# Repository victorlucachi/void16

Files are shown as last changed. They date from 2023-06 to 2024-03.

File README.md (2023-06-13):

# VOID16
*A 4x4 handwired macropad*

VOID16

The VOID16 is a 3d printed, handwired, 4x4 macropad running QMK Firmware on a Pro Micro controller.

I suggest printing the case using a 0.4 mm nozzle, supports are not needed for any of the parts.

You might want/need to use small dabs of hot glue to secure the switches in the plate depending on how well calibrated your printer is (if you're generous with it, it will add to the weight of the keyboard and it might change the feel of it).

Dont overtighten the screws as the threads might get stripped.

# Handwiring guide

I've also put together a pretty visual handwiring guide for the VOID9, that you can browse over [here](https://victorlucachi.ro/journal/void9-wiring-guide/).

|  	|  	|  	|
|---|---|---|

# Bill Of Materials

* 16 x diodes ([tme.eu](https://www.tme.eu/ro/en/details/1n4148-dio/tht-universal-diodes/diotec-semiconductor/1n4148/)/[aliexpress](https://www.aliexpress.com/item/32729204179.html))
* 16 x Cherry MX style mechanical switches
* 16 x keycaps of choice
* 1 x Pro Micro ([aliexpress](https://www.aliexpress.com/item/32902569443.html))
* 1 x EC11 Rotary Encoder ([aliexpress](https://www.aliexpress.com/item/32872039030.html)/mounted to the plate using [this adapter](https://www.thingiverse.com/thing:3770166))
* 24 AWG (0.2 mm2) wire
* 4 x 8mm bumpons

### Redux
* 6 x M2x3x3.5 OD heat inserts ([aliexpress](https://www.aliexpress.com/item/4000585933306.html?spm=a2g0o.order_list.order_list_main.33.21ef1802vdSNrS))
* 4 x M2x10 Allen head screws ([aliexpress](https://www.aliexpress.com/item/32966941844.html?spm=a2g0o.order_detail.order_detail_item.9.722ff19cyjrixq))
* 2 x M2x6 Countersunk screws ([aliexpress](https://www.aliexpress.com/item/32968097507.html?spm=a2g0o.order_list.order_list_main.32.21ef1802vdSNrS))

### V1
* 4 x M3x10 allen head screws ([tme.eu](https://www.tme.eu/ro/en/details/m3x10_d912-a2/bolts/kraftberg/)/[aliexpress](https://www.aliexpress.com/item/32966941844.html))
* hotglue

# Pin assignment

    ROW0    ROW1    ROW2    ROW3
    D3      D2      D1      D0

    COL0    COL1    COL2    COL3
    E6      D7      C6      D4

    Encoder Pad A           Encoder Pad B
    F5                      F4

# QMK Vial Fork

A QMK Vial fork can be found [here](https://github.com/victorlucachi/vial-qmk/tree/dev_void/keyboards/handwired/void16).

Most features are disabled in order for the firmware to fit on the atmega32u4 present on the Pro Micro controllers, but if you want to tinker around with different features or if you're using a different MCU you can enable/disable them to suit your own needs by editing the rules.mk file in the vial keymap folder.

The web version of Vial is available at [vial.rocks](https://vial.rocks/); it runs in supported browsers (Chrome, Edge and Opera) without requiring an installation.

VOID16 Vial

# QMK Fork

A fork containing the QMK config files can be found [here](https://github.com/victorlucachi/qmk_firmware/tree/dev_void/keyboards/handwired/void16). Edit them to suit your own needs and build the firmware following the QMK docs.

If you plan on using the VIA configurator dont forget to download the json definitions file linked in this repository.



This work is licensed under a [Creative Commons Attribution-NonCommercial-ShareAlike 4.0 International License](https://creativecommons.org/licenses/by-nc-sa/4.0/).

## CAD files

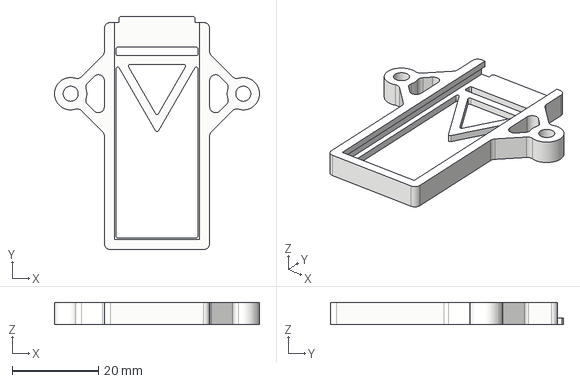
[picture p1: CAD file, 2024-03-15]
Redux/STEP/Controller/51x21mm - Pi Pico - Flat.step
47.5 x 54.0 x 5.16 mm

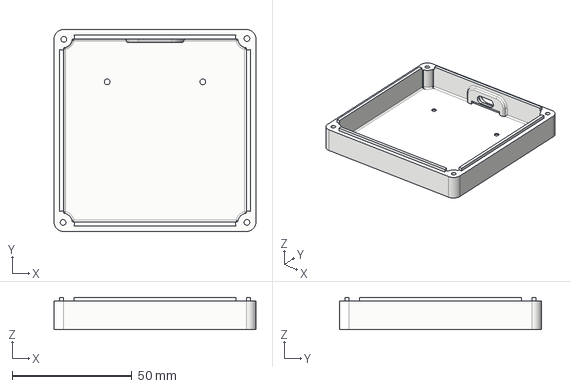
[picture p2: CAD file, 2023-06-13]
Redux/STEP/VOID16 Redux - Bottom - Flat.step
84.5 x 84.5 x 13.5 mm

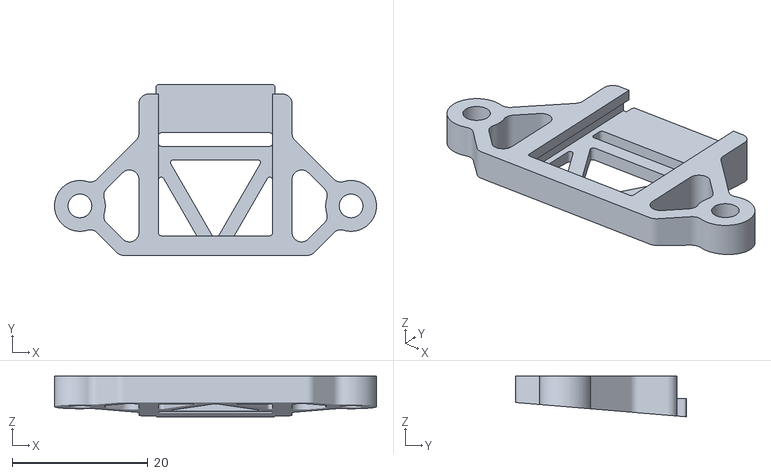
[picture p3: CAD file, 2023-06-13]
Redux/STL/Controller/21.5x18mm - Seeed Xiao - Angled.stl
47.5 x 25.2 x 6.00

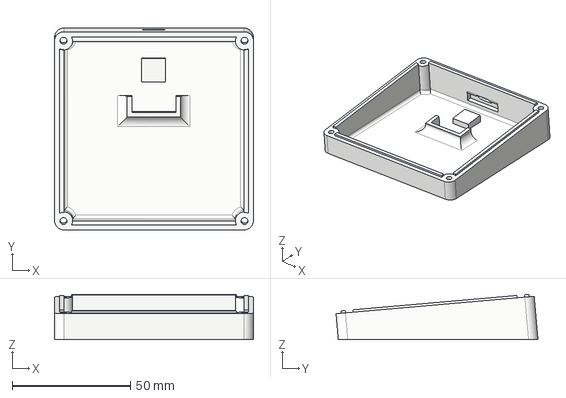
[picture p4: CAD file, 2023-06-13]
v1/STEP/VOID16 - Bottom.step
84.2 x 85.5 x 19.1 mm

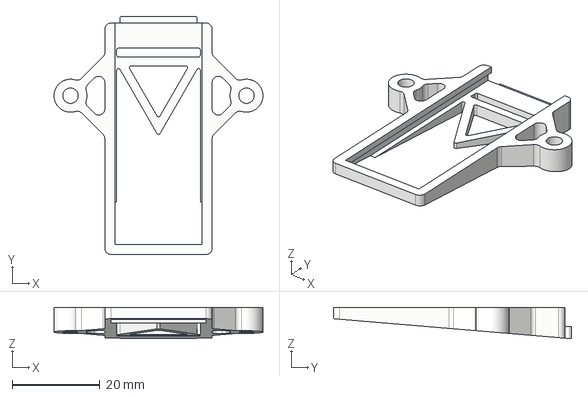
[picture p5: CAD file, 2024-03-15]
Redux/STEP/Controller/51x21mm - Pi Pico - Angled.step
47.5 x 54.1 x 7.14 mm

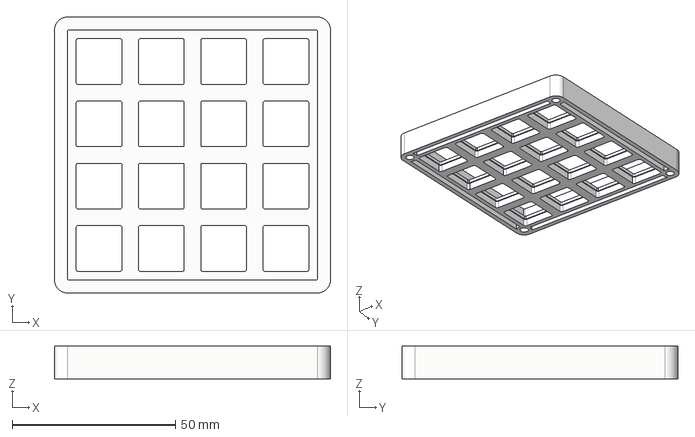
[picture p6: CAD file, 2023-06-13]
Redux/STEP/VOID16 Redux - Top - Flat.step
84.5 x 84.5 x 10.0 mm

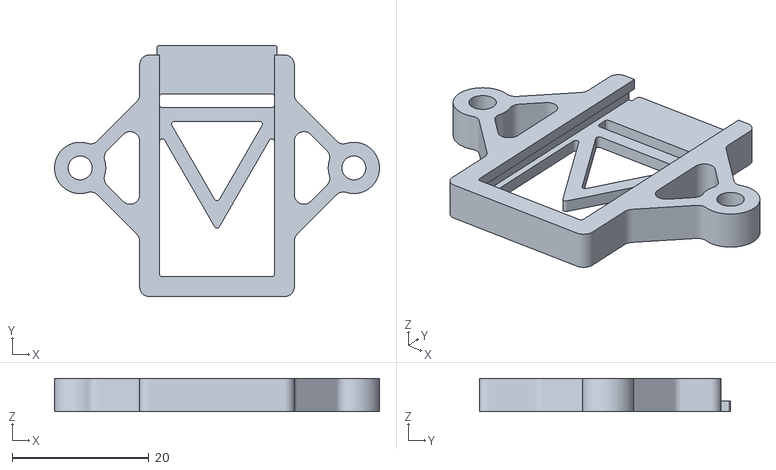
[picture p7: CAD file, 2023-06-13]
Redux/STL/Controller/33x18mm - Pro Micro - Flat.stl
47.5 x 36.7 x 4.86

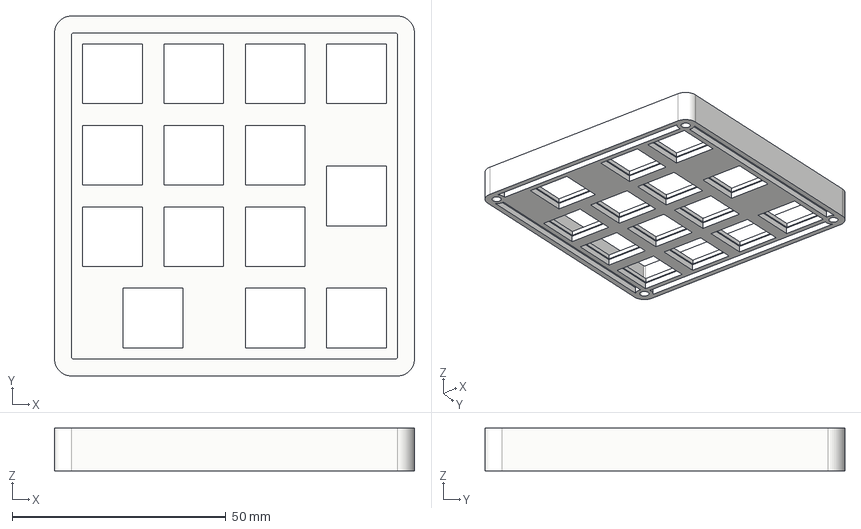
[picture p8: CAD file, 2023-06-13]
v1/STEP/VOID16 - Top - Alternate Layout.step
84.2 x 84.2 x 10.0 mm

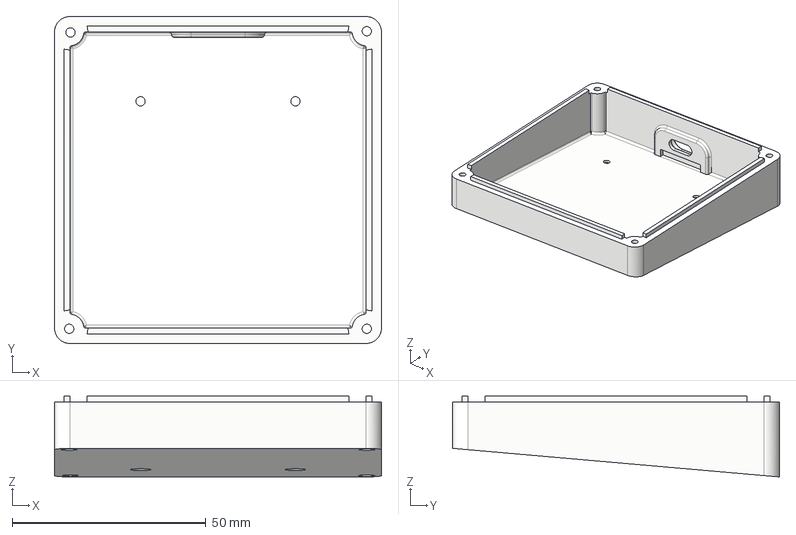
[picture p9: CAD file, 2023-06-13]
Redux/STEP/VOID16 Redux - Bottom - Angled.step
84.5 x 84.5 x 20.9 mm

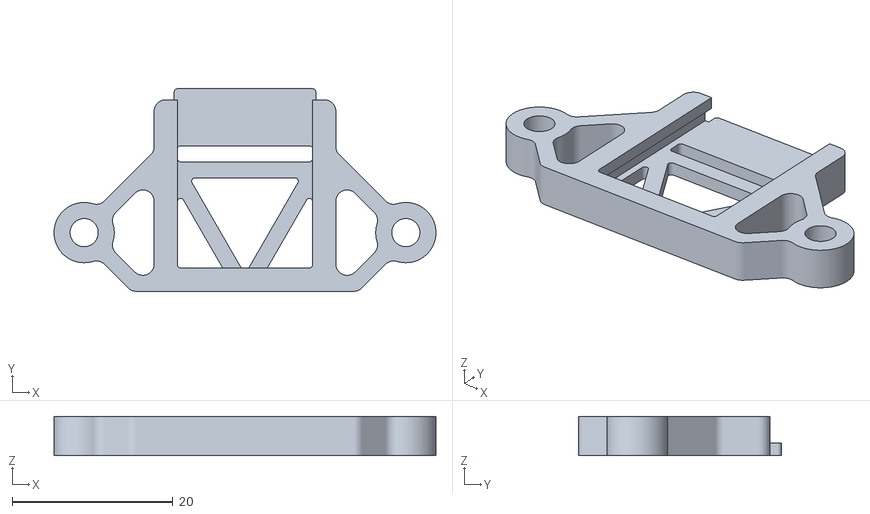
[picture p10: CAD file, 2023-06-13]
Redux/STL/Controller/21.5x18mm - Seeed Xiao - Flat.stl
47.5 x 25.2 x 4.86

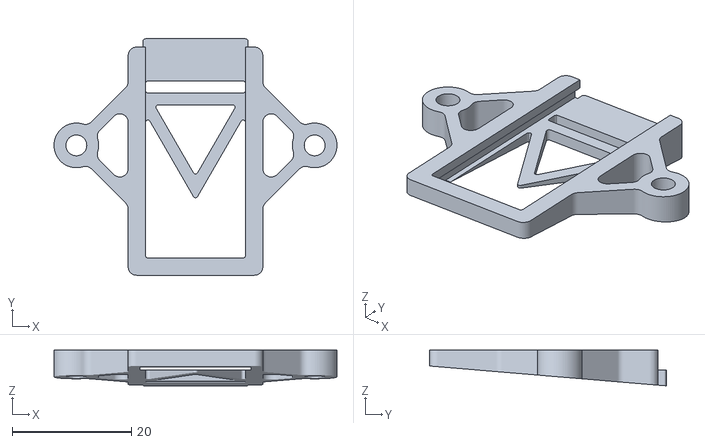
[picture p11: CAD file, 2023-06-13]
Redux/STL/Controller/36x18mm - Type C Pro Micro - Angled.stl
47.5 x 39.7 x 6.00

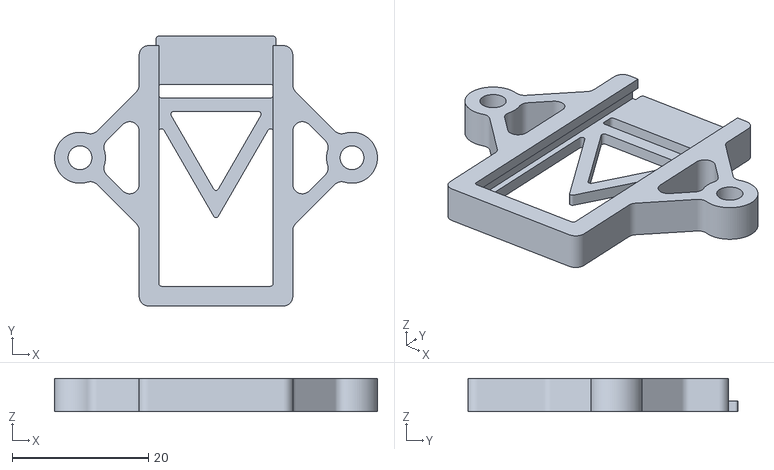
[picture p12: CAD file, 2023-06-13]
Redux/STL/Controller/36x18mm - Type C Pro Micro - Flat.stl
47.5 x 39.7 x 4.86

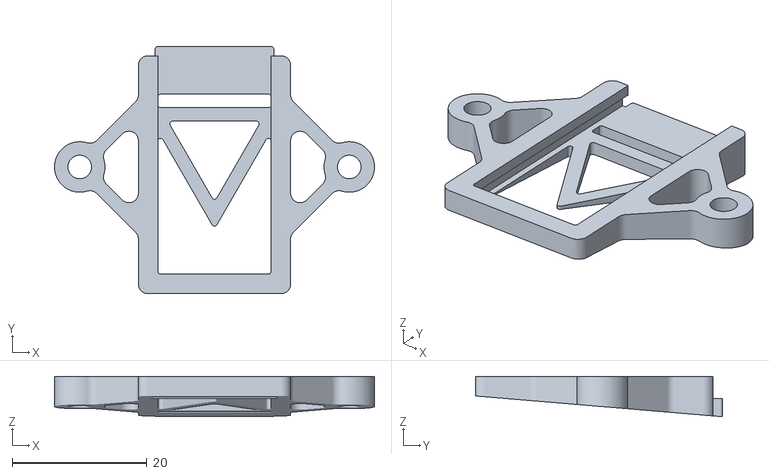
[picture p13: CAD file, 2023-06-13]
Redux/STL/Controller/33x18mm - Pro Micro - Angled.stl
47.5 x 36.7 x 6.00

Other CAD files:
v1/STEP/VOID16 - Top.step
Redux/STL/Controller/51x21mm - Pi Pico - Angled.stl
Redux/STL/Controller/51x21mm - Pi Pico - Flat.stl
Redux/STL/VOID16 Redux - Bottom - Angled.stl
Redux/STL/VOID16 Redux - Bottom - Flat.stl
Redux/STL/VOID16 Redux - Top - Flat.stl
v1/STL/VOID16 - Bottom.stl
v1/STL/VOID16 - Top - Alternate Layout.stl
v1/STL/VOID16 - Top.stl

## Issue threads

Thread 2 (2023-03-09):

bought from your material list but the pro micro is not recognized, im wondering if you had the same issue?

loseryoda, 2023-03-09:
i bought the 5v micro usb one by mistake but installing a lot of drivers i'm still unable to get it recognized.

victorlucachi, 2023-03-11:
except for the usb port and layout differences, functionally they're all the same; the 3d models however are designed around the micro usb variant of the controller, which has 33mm in length.

having said that, I dont know what os you're using, but on windows qmk toolbox should install the required drivers; once you connect the controller to your computer in bootloader mode it should show up under com ports.

loseryoda, 2023-03-12:
FYI, yes i noticed the usb-C variant was too long, but buying from your material list it appears that the aliexpress listing is wrong and they're actually selling a 32u4rc instead of a 32u4 which has no bootloader and is basically unusable without a programmer.
might want to note that.

Closed 2023-06-13.

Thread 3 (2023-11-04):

Controller mount .step files

lendunistus, 2023-11-04:
hey! wanted to build your project but I don't happen to have a Pro Micro handy, so I'm making a controller mount for the Raspberry Pi Pico. I noticed that you don't have .step files for the redux controller mounts, so I'm trying to get measurements and such off the .stl files (which is quite a pain).

could you please maybe put the .step files for those in the repository as well? it'd be quite helpful to both me and others. thanks!

victorlucachi, 2023-11-06:
> hey! wanted to build your project but I don't happen to have a Pro Micro handy, so I'm making a controller mount for the Raspberry Pi Pico. I noticed that you don't have .step files for the redux controller mounts, so I'm trying to get measurements and such off the .stl files (which is quite a pain).
>
> could you please maybe put the .step files for those in the repository as well? it'd be quite helpful to both me and others. thanks!

hello. added both stl and step files. the Pico is rather long and it might not work well with the angled version of the case/mount, please let me know if you encounter any issues.

lendunistus, 2024-03-14:
finally got to this. the mount appears to fit fine, but the front edge that slots into the case isn't centered:
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

this ends up making the screw alignment kind of awkward:
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

I'll try to get to modifying it myself sometime. thank you (and apologies for the wait)!

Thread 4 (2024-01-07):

How to solder ec11 to pro micro

vibetribe482, 2024-01-07:
Hello! Can you please show how to solder encoder to pro micro? In your assembly guide there is only 2 pins, but encoder have 5 pins. Thank you.

victorlucachi, 2024-01-07:
> Hello! Can you please show how to solder encoder to pro micro? In your assembly guide there is only 2 pins, but encoder have 5 pins. Thank you.

Hey, the two pins on the left are wired into the switch matrix, and on the right side the middle pin to ground, out A and out B to the pins mentioned in the pinout. Hope this makes things clearer.

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

vibetribe482, 2024-01-07:
Thank you for suck a quick response! Now it’s clear enough. Have a nice day!

Closed 2024-01-07.

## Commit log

2021-04-01 Added .step files
    [VOID16 - Bottom.step, VOID16 - Top - Alternate Layout.step, VOID16 - Top.step]
2023-06-13 redux prep
    - restructured repo
    - added precompiled fw
    - prep for redux models
    [VOID16 - Bottom.step, VOID16 - Bottom.stl, VOID16 - Top - Alternate Layout.step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]
2023-06-13 VOID16 Redux
    - added redux models
    - modular pro micro controller mount
    - m2 hardware
    - m2 brass inserts
    [VOID16 Redux - Bottom - Angled.step, VOID16 Redux - Bottom - Angled.stl, VOID16 Redux - Bottom - Flat.step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]
2023-06-13 properly export step files
    [VOID16 Redux - Pro Micro - Angled.step]
2023-06-13 modular controller mounts
    - added modular mounts for a couple of controllers
    [21.5x18mm - Seeed Xiao - Angled.stl, 21.5x18mm - Seeed Xiao - Flat.stl, 23.5x18mm - Waveshare rp2040 zero - Angled.stl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]
2023-07-03 removed waveshare controller mount
    [23.5x18mm - Waveshare rp2040 zero - Angled.stl, 23.5x18mm - Waveshare rp2040 zero - Flat.stl]
2023-11-06 added Pi Pico controller mounts
    added step and stl controller mount files for the Pi Pico
    [51x21mm - Pi Pico - Angled.step, 51x21mm - Pi Pico - Angled.stl, 51x21mm - Pi Pico - Flat.step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]
2024-03-15 fixed offset pico mounts
    [51x21mm - Pi Pico - Angled.step, 51x21mm - Pi Pico - Angled.stl, 51x21mm - Pi Pico - Flat.step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]

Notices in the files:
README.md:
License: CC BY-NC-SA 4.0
